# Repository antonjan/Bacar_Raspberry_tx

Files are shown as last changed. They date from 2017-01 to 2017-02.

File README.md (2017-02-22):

This board is now compleet. Testing will start shortely.

This repository will have all the files for the PCB that fits on a Raspberry Pi witch will have a 7 stage low pass filter for the VHF 2m band. (About 60db down for first harmonic).<br>
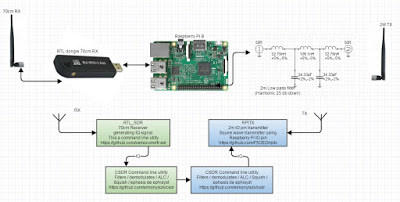
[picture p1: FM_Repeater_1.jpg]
Block diagram
<br>
It also now include a Mini Circuits low pass filter so you could use this board for two bands.
Operating manual will be available shortly.
This board is to be used with the rpitx utility to alow you to transmit on the 2m VHF band.
This board will have 7 stage lowpass filter.<br>
Here is the filter design details.<br>

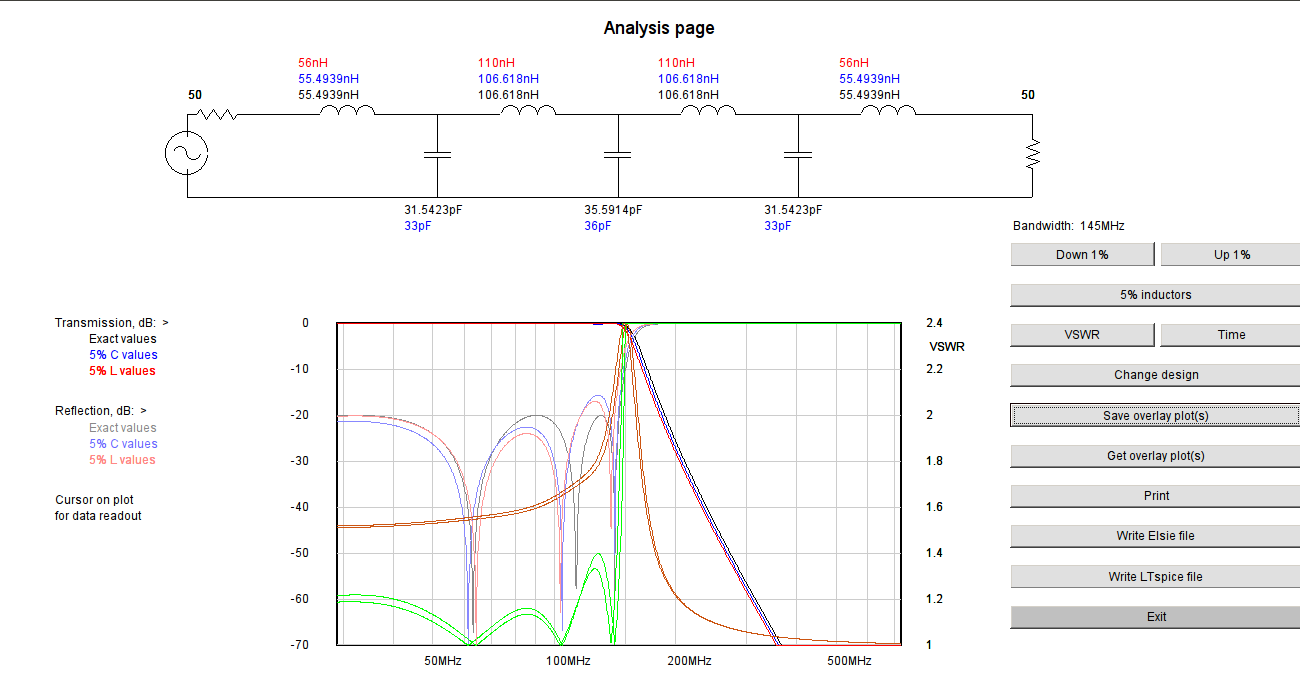
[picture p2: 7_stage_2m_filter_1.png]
Filter diagram
<br>
Filter similator Diagram<br>
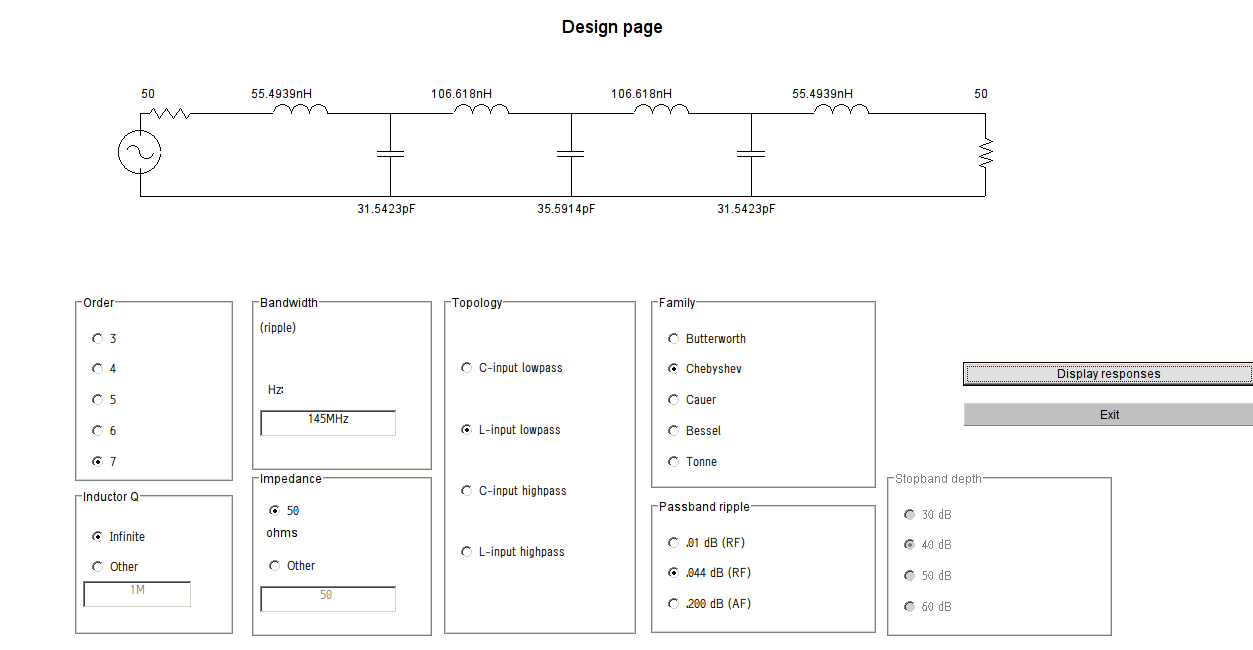
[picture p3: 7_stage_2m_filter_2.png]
Filter diagram

The PCB files is Kicad file format.<br>
The circuit diagram.<br>

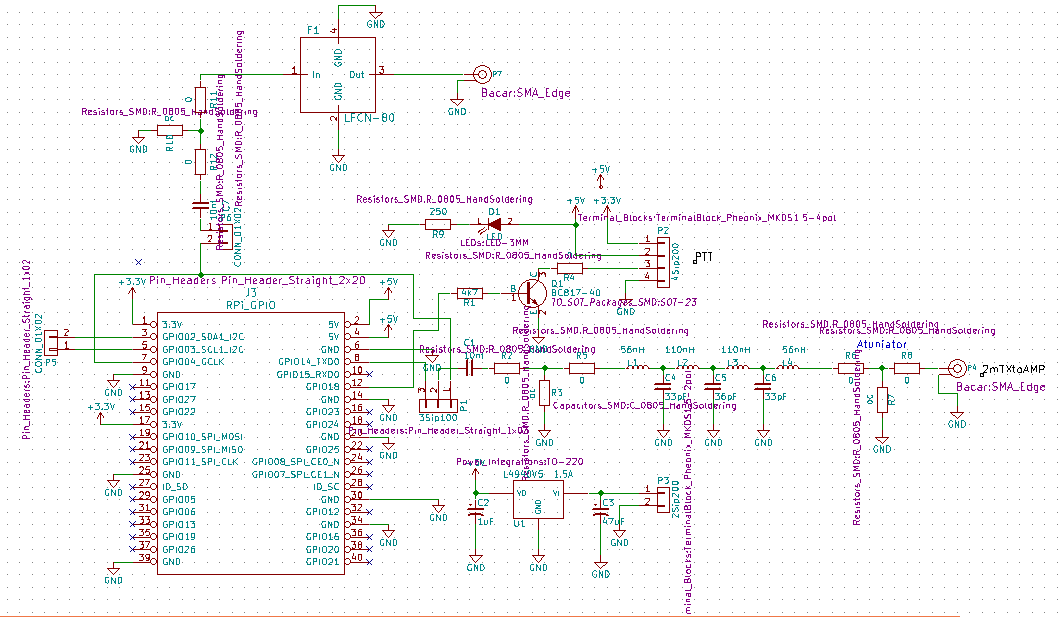
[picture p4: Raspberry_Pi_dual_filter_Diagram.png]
Raspberry Pi hat Circuit diagram

PCB layout diagram during design
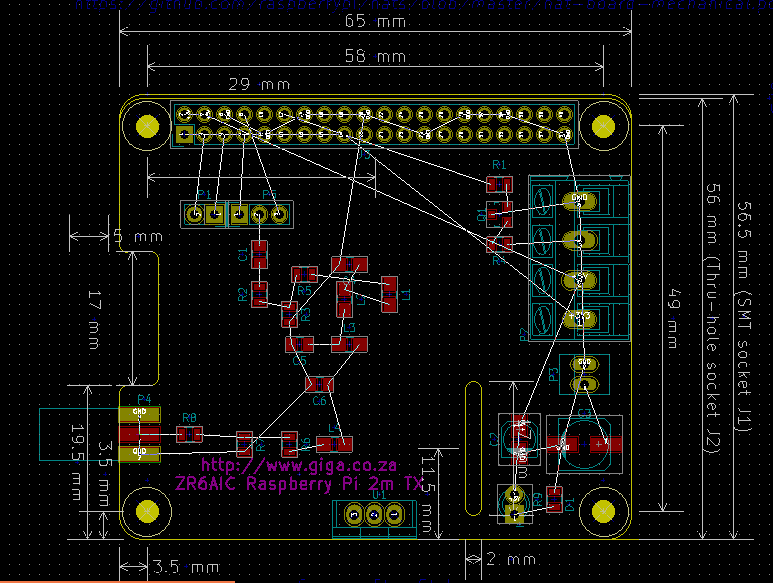
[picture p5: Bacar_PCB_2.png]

<br>
Chnaged Connectors transistor and regulator
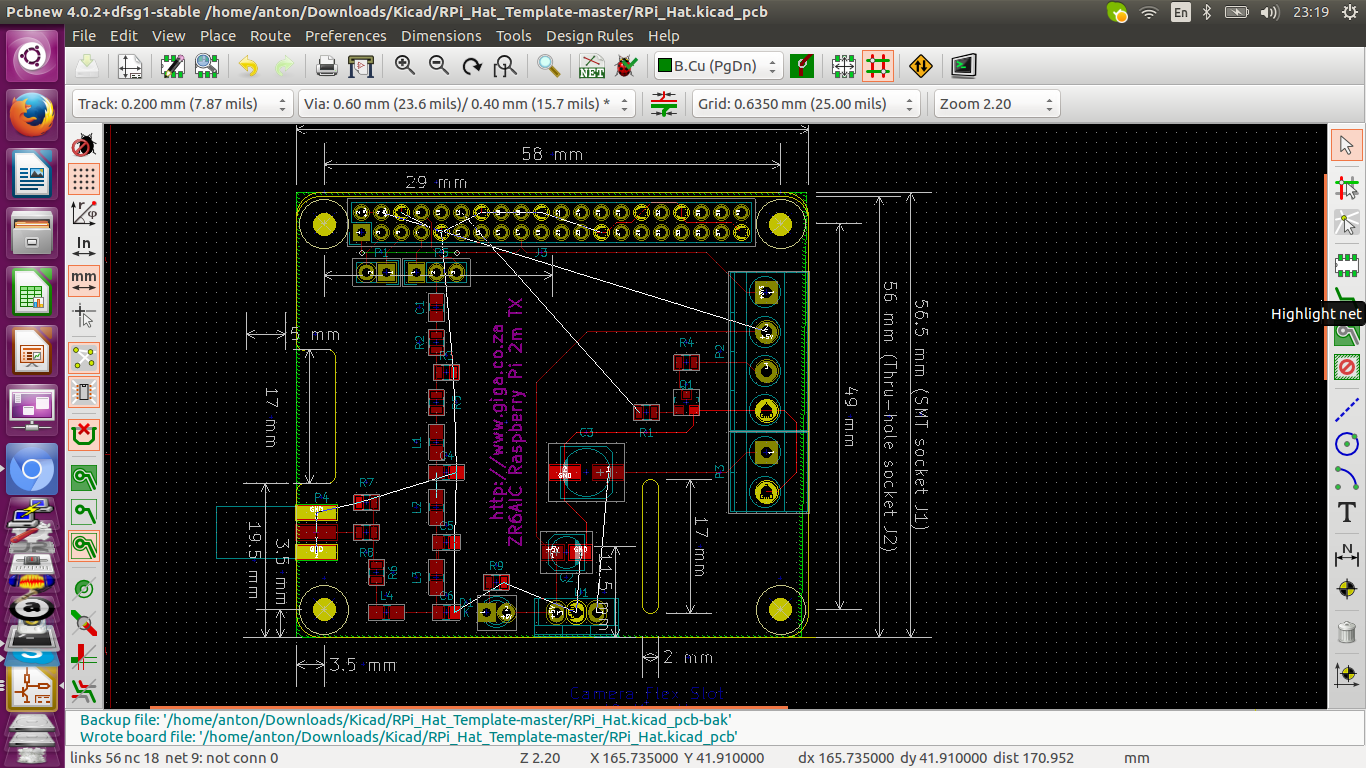
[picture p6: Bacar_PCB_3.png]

<br>
PCB 3D view
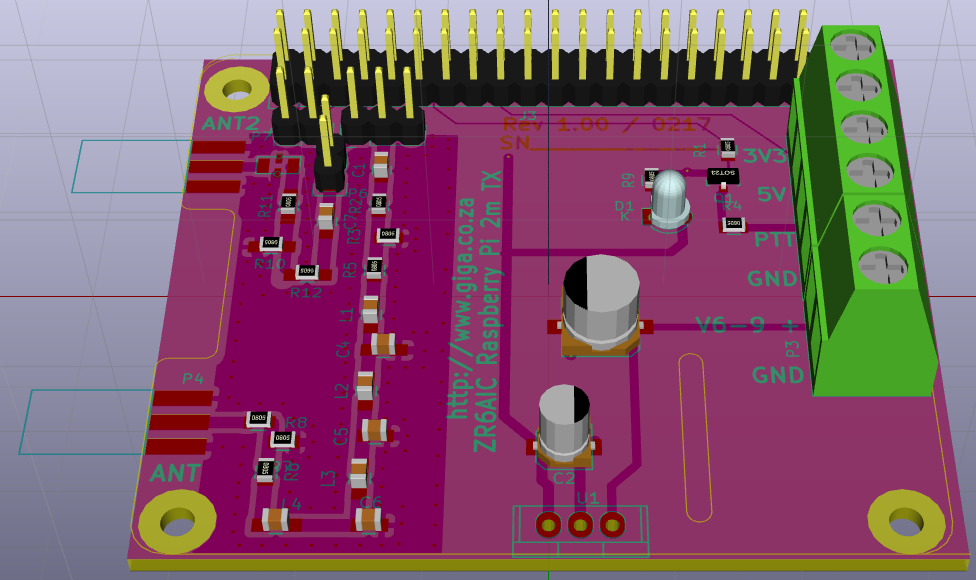
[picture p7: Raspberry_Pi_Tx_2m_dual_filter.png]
PCB 3D Layout

Top SMA Connector is linkd to one filter.
Botom SMA connector is connected to 7 stage filter.
<br>
3DB RF Attenuator T (Kicad)
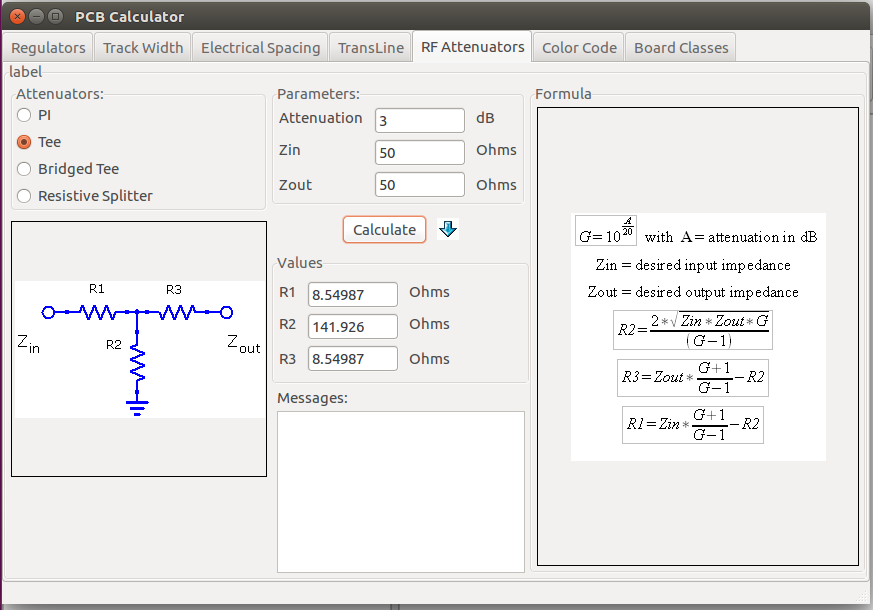
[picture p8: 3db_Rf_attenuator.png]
3db rf Attenuator

<br>
6dB Rf attenuator T (Kicad)
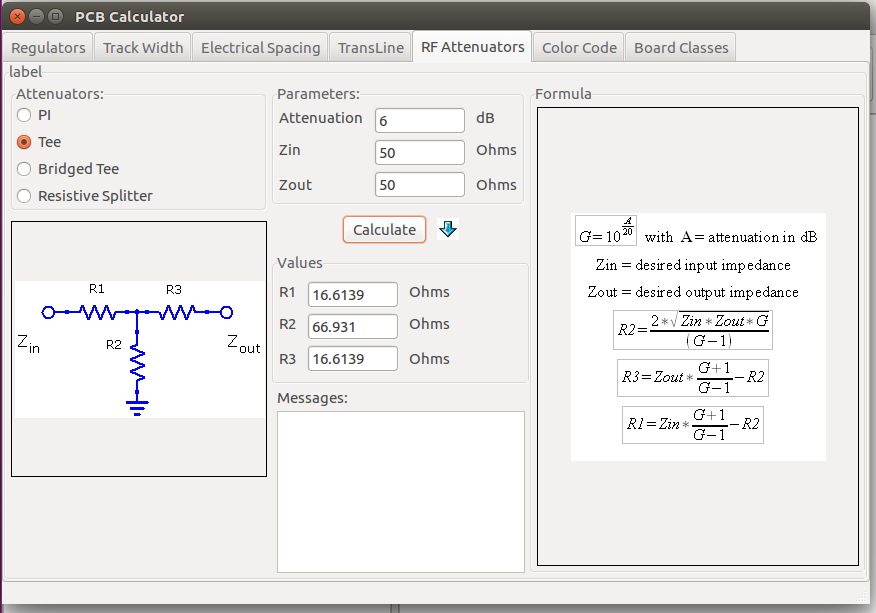
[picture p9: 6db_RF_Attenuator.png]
6db rf Attenuator

<br>
9dB Rf attenuator T (Kicad)
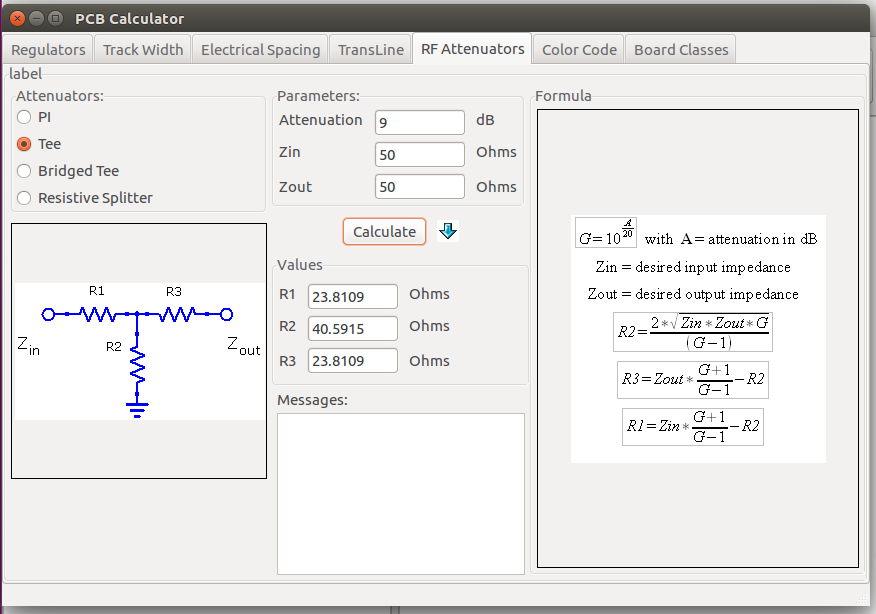
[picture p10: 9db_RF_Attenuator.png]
6db rf Attenuator

<br>
PCB wave guide with Ground plane impedance calculator 50ohm (Kicad)
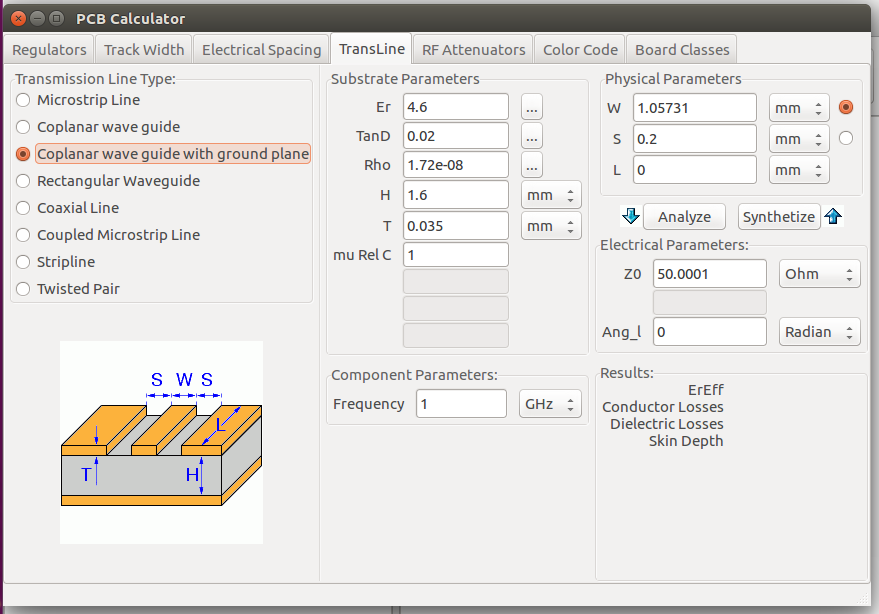
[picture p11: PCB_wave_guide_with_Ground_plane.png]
9db rf Attenuator

<br>

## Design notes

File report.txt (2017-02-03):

Plot: '/home/anton/Downloads/Kicad/RPi_Hat_Template-master/meta/Raspberry_Pi_2m_TX_2-F.Cu.svg' OK.
Plot: '/home/anton/Downloads/Kicad/RPi_Hat_Template-master/meta/Raspberry_Pi_2m_TX_2-B.Cu.svg' OK.
Plot: '/home/anton/Downloads/Kicad/RPi_Hat_Template-master/meta/Raspberry_Pi_2m_TX_2-B.SilkS.svg' OK.
Plot: '/home/anton/Downloads/Kicad/RPi_Hat_Template-master/meta/Raspberry_Pi_2m_TX_2-F.SilkS.svg' OK.

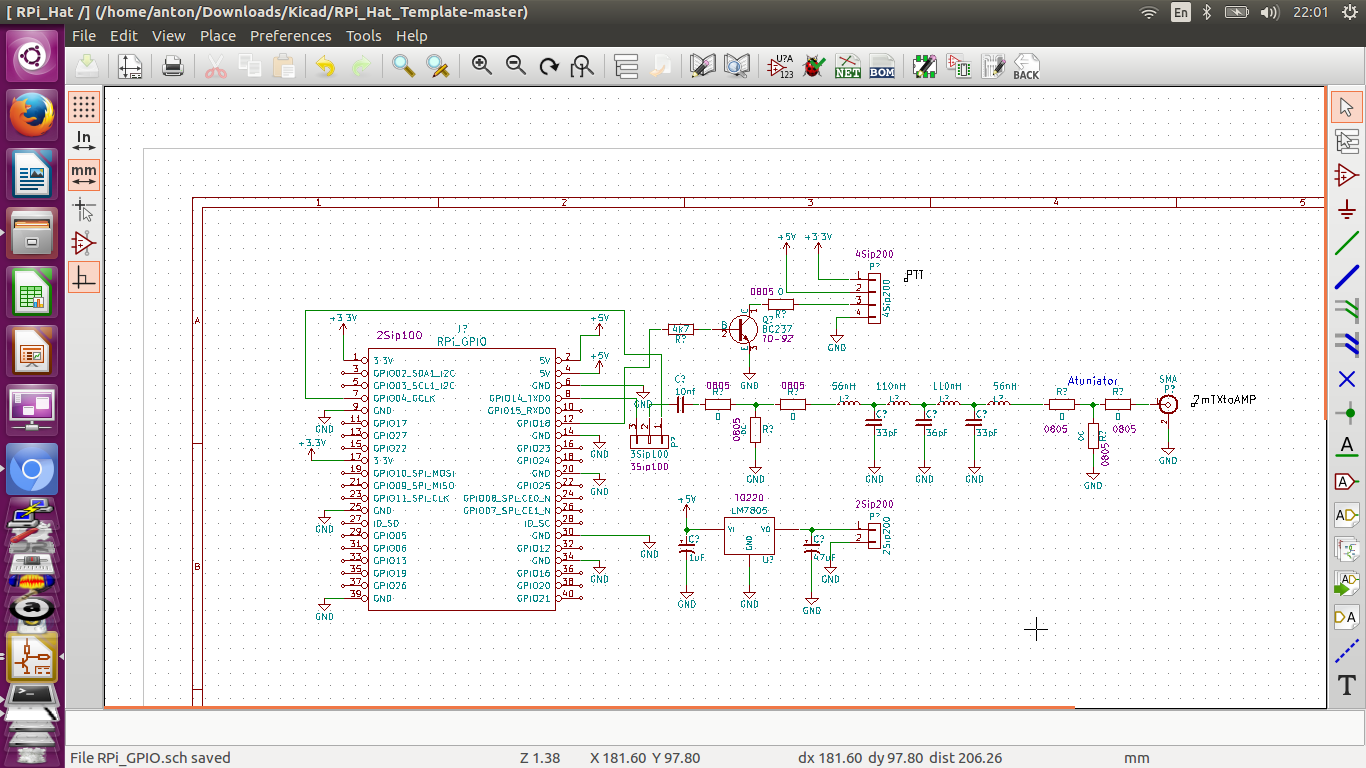
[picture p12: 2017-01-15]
SDR_Raspberry_tx_1.png

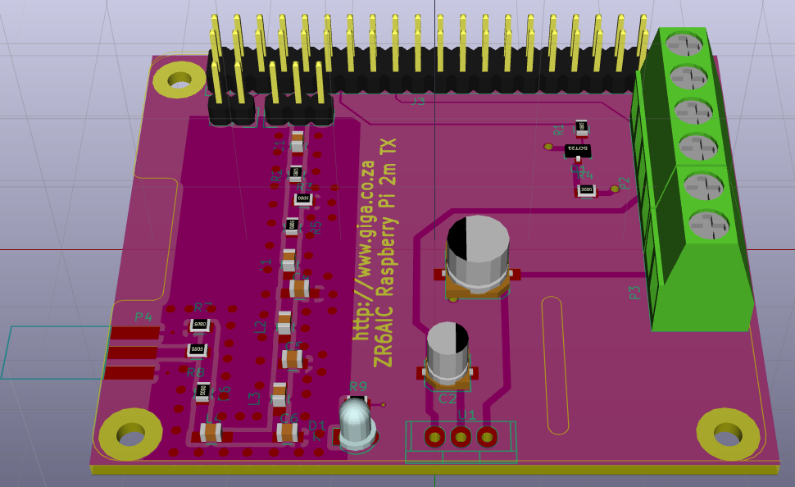
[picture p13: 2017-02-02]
PCB_3D_Model.png

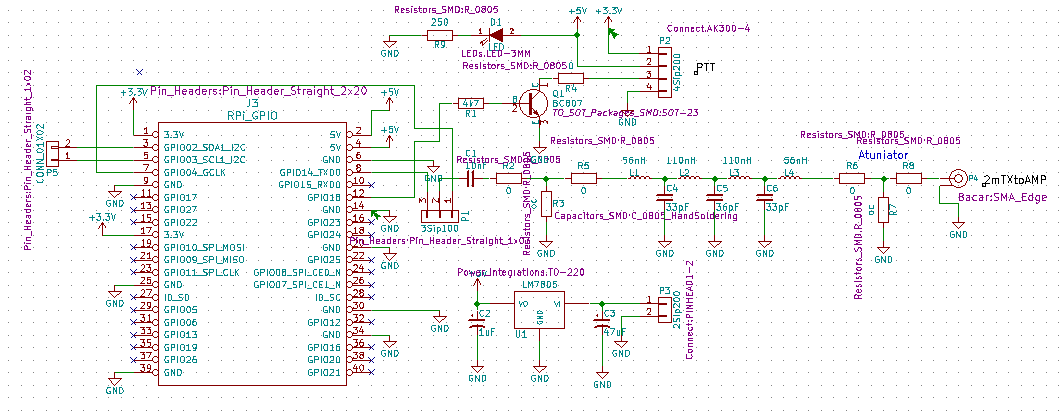
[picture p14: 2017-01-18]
Bacar_s_diagram.png

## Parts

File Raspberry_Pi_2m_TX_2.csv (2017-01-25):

Id | Designator | Package | Quantity | Designation | Supplier and ref
1 | ,,, | RPi_Hat_Mounting_Hole | 4
2 | C1 | C_0805 | 1 | 10nf
3 | C2 | c_elec_4x5.7 | 1 | 1uF
4 | C3 | c_elec_6.3x5.7 | 1 | 47uF
5 | C4 | C_0805_HandSoldering | 1 | 33pF
6 | C5 | C_0805 | 1 | 36pF
7 | C6 | C_0805 | 1 | 33pF
8 | D1 | LED-3MM | 1 | LED
9 | J3 | Pin_Header_Straight_2x20 | 1 | RPi_GPIO
10 | L1,L4 | C_0805_HandSoldering | 2 | 56nH
11 | L2,L3 | C_0805_HandSoldering | 2 | 110nH
12 | P1 | Pin_Header_Straight_1x03 | 1 | 3Sip100
13 | P4 | SMA_Edge | 1 | SMA
14 | P5 | Pin_Header_Straight_1x02 | 1 | CONN_01X02
15 | R1 | R_0805 | 1 | 4k7
16 | R2,R4,R5,R6,R8 | R_0805 | 5 | 0
17 | R3,R7 | R_0805 | 2 | oc
18 | R9 | R_0805 | 1 | 250
19 | U1 | TO-220 | 1 | L4940V5 1.5A
20 | P2 | TerminalBlock_Pheonix_MKDS1.5-4pol | 1 | 4Sip200
21 | P3 | TerminalBlock_Pheonix_MKDS1.5-2pol | 1 | 2Sip200
22 | Q1 | SOT-23 | 1 | BC817-40

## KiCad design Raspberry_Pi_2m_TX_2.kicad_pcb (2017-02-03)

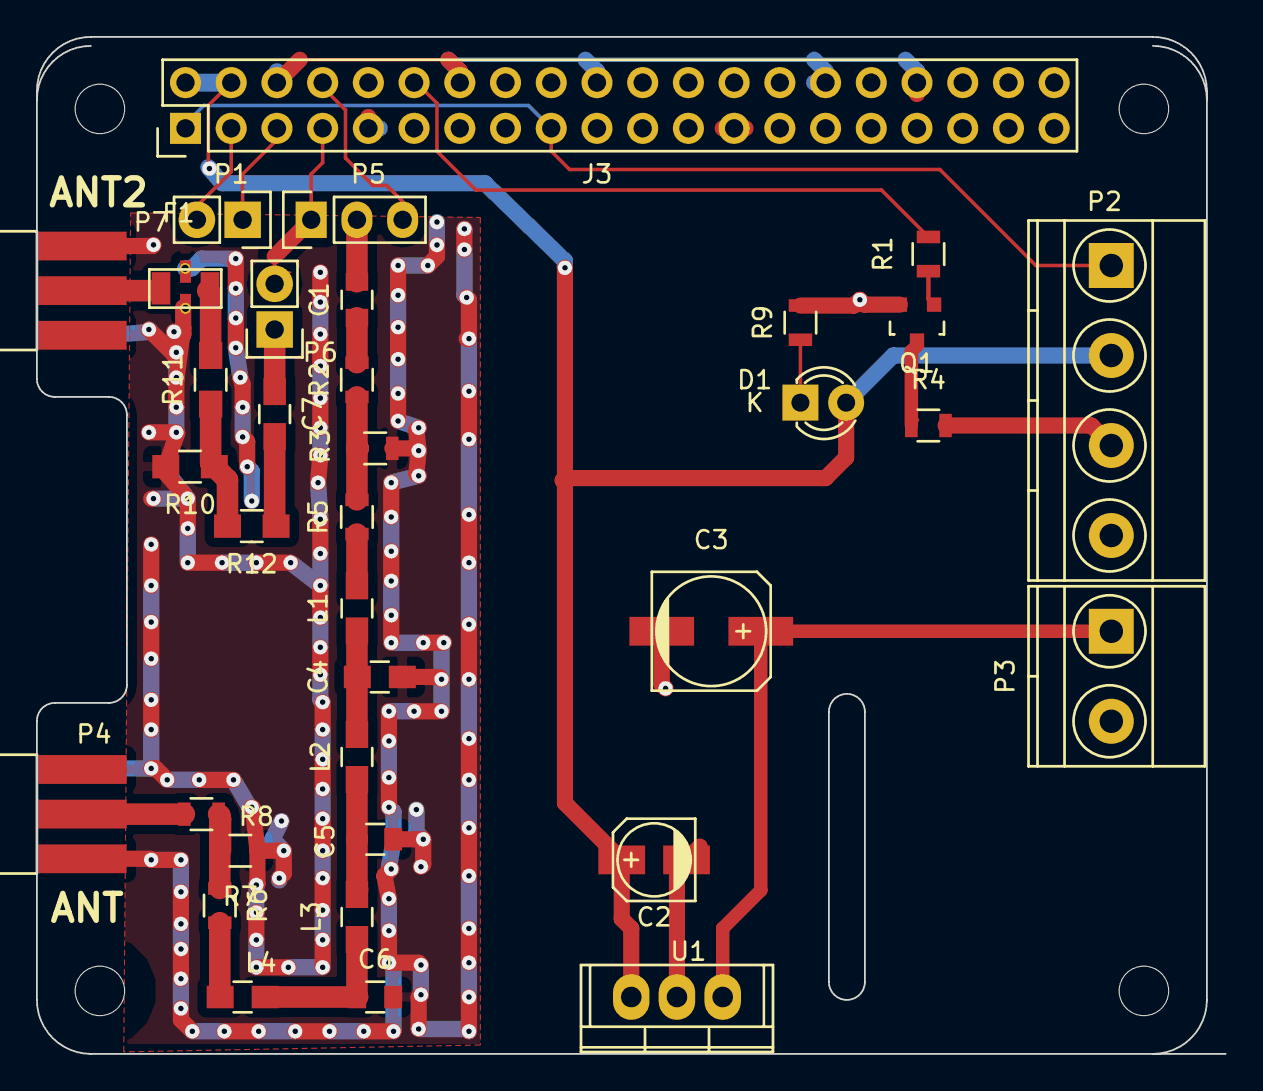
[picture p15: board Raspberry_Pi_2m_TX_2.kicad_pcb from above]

Board: 2 copper layers, 66.0 x 56.5 mm, 35 parts (0 on the bottom side), 28 nets.

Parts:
C1: 10nf; C_0805
C2: 1uF; c_elec_4x5.7
C3: 47uF; c_elec_6.3x5.7
C4: 33pF; C_0805_HandSoldering
C5: 36pF; C_0805
C6: 33pF; C_0805
C7: 10nf; C_0805_HandSoldering
D1: LED; LED-3MM
F1: LFCN-80
J3: RPi_GPIO; Pin_Header_Straight_2x20
L1, L4: 56nH; C_0805_HandSoldering
L2, L3: 110nH; C_0805_HandSoldering
P1: 3Sip100; Pin_Header_Straight_1x03
P2: 4Sip200; TerminalBlock_Pheonix_MKDS1.5-4pol
P3: 2Sip200; TerminalBlock_Pheonix_MKDS1.5-2pol
P4, P7: SMA; SMA_Edge
P5, P6: CONN_01X02; Pin_Header_Straight_1x02
Q1: BC817-40; SOT-23
R1: 4k7; R_0805
R2, R4, R5, R6, R8: 0; R_0805
R3, R7: oc; R_0805
R9: 250; R_0805
R10: oc; R_0805_HandSoldering
R11, R12: 0; R_0805_HandSoldering
U1: L4940V5 1.5A; TO-220

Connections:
+3V3: J3.1, J3.17, P2.1
+5V: C2.1, D1.2, J3.2, J3.4, P2.2, U1.3
GND: C2.2, C3.2, C4.2, C5.2, C6.2, F1.2, F1.4, J3.6, J3.9, J3.14, J3.20, J3.25, J3.30, J3.34, J3.39, P2.4, P3.2, P4.2, P7.2, Q1.2, R3.2, R7.2, R9.2, R10.2, U1.2
unnamed: C1.1, R2.2
unnamed: C1.2, P1.2
unnamed: C3.1, P3.1, U1.1
unnamed: C4.1, L1.2, L2.1
unnamed: C5.1, L2.2, L3.1
unnamed: C6.1, L3.2, L4.2
unnamed: C7.1, P6.1
unnamed: C7.2, R12.1
unnamed: D1.1, R9.1
unnamed: F1.1, R11.2
unnamed: F1.3, P7.1
unnamed: J3.3, P5.2
unnamed: J3.5, P5.1
unnamed: J3.7, P1.1, P6.2
unnamed: J3.8, P1.3
unnamed: J3.12, R1.2
unnamed: L1.1, R5.1
unnamed: L4.1, R6.2
unnamed: P2.3, R4.1
unnamed: P4.1, R8.1
unnamed: Q1.1, R1.1
unnamed: Q1.3, R4.2
unnamed: R2.1, R3.1, R5.2
unnamed: R6.1, R7.1, R8.2
unnamed: R10.1, R11.1, R12.2

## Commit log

2017-01-15 Loading the first diagrams
    [RPi_GPIO.sch, RPi_Hat.kicad_pcb, RPi_Hat.sch]
2017-01-15 Loading filter Design diagrams
2017-01-17 added annotation and module details
    sma connector footprint still not corect
    [RPi_Hat.sch, _saved_RPi_Hat.sch]
2017-01-18 Created SMA footprint and started laying out board
    [RPi_GPIO.sch, RPi_Hat.sch]
2017-01-18 Added filter digram link
2017-01-18 Added Filter similator diagram
2017-01-18 Added Picture of circuit diagram
    Added Picture of circuit diagram if you don't have Kicad
2017-01-18 added circuit diagram
2017-01-18 PCB layout diagram
2017-01-18 Added PCB Diagram
2017-01-19 Placing components
    [RPi_Hat.kicad_pcb]
2017-01-25 Change Regulator transistor and connectors
    Change Regulator transistor and connectors
    Started laying out PCB
    [RPi_Hat.csv, RPi_Hat.kicad_pcb, RPi_Hat.sch]
2017-01-31 Added updated pcb
    [Raspberry_Pi_2m_TX.csv, Raspberry_Pi_2m_TX.kicad_pcb, Raspberry_Pi_2m_TX_2.kicad_pcb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]
2017-02-02 Low pass filter data
2017-02-02 Finished PCB but still need to do DRC
    Almost complete
    Still need to DRC and component check
    [Raspberry_Pi_2m_TX_2.kicad_pcb]
2017-02-02 Added 3D View of PCB
2017-02-03 Board is now Compleet
    Added second filter
    [Raspberry_Pi_2m_TX_2-NPTH.drl, Raspberry_Pi_2m_TX_2.drl]
2017-02-03 Board is now compleate
    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
    [Raspberry_Pi_2m_TX_2.csv, Raspberry_Pi_2m_TX_2.kicad_pcb, Raspberry_Pi_2m_TX_LPF_7Stage.sch]
2017-02-15 Added 3d view of dual filter board
2017-02-15 added updated dual filter Diagram
2019-05-04 add from
    https://jacobzelek.com/posts/2016-04-24-raspberry-pi-sdr/
